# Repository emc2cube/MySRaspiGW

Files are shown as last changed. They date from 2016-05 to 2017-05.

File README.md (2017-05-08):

MySRaspiGW
==========

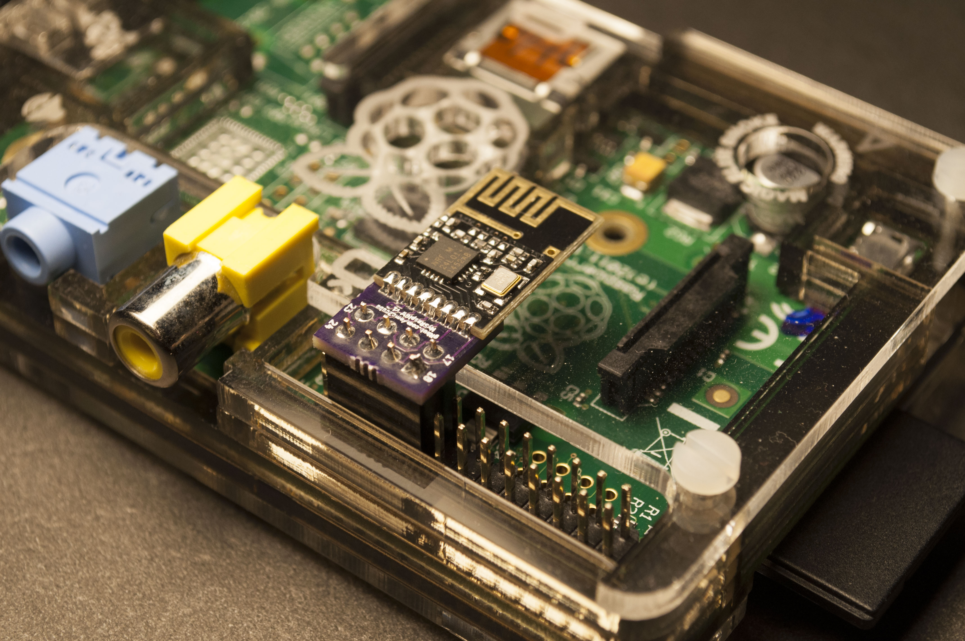
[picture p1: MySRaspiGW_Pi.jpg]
GW on the Pi

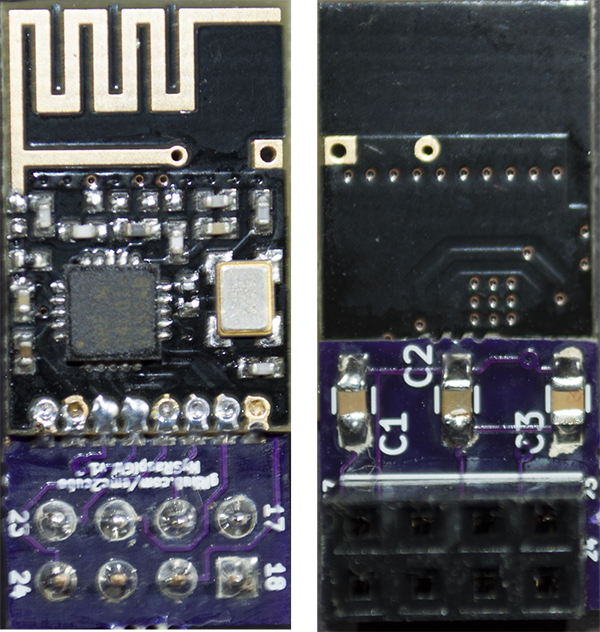
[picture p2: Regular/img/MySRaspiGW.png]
Regular GW

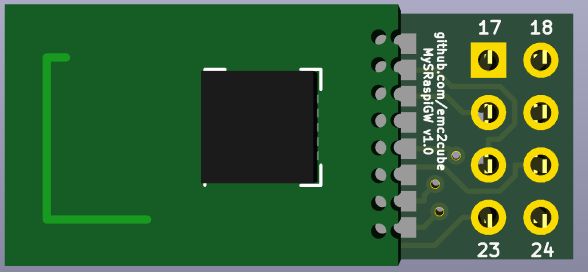
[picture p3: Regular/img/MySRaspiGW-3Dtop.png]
KiCad 3D view


Description
-----------

[MySensors](http://www.mysensors.org) SMD gateway (nRF24L01, 2.4GHz) designed to fit Raspberry Pi GPIO ports.
This is the SMD shrunk version of GertSanders [Raspberry Pi2 GPIO interface for NRF24L01+](https://www.openhardware.io/view/17/Raspberry-Pi2-GPIO-interface-for-NRF24L01).

Ordering and options
--------

Four different models are available, differences being the radio used (standard or PA+LNA modules) and the PCB shape.

### Standard nRF24L01 module version:
- Regular version is the smallest form factor available. Radio module is straight with GPIO pins.
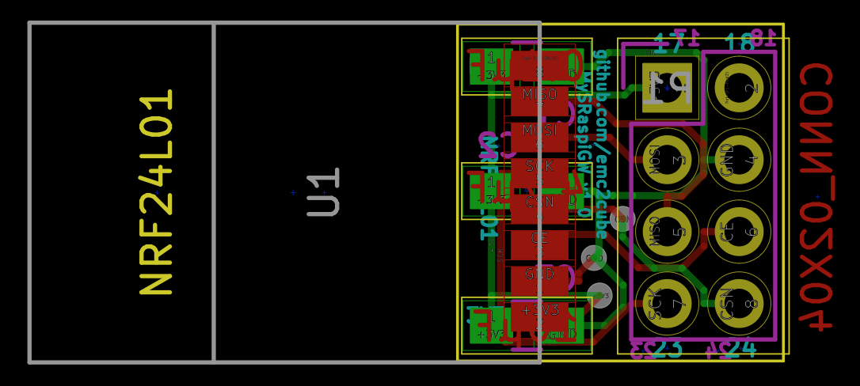
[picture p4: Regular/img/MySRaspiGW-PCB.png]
MySRaspiGW regular PCB


- Pimoroni version is designed to fit inside the popular [Pimoroni](http://pimoroni.com) cases designed for the original Raspberry Pi model B, such as [Pibow](https://www.raspberrypi.org/blog/pibow/).
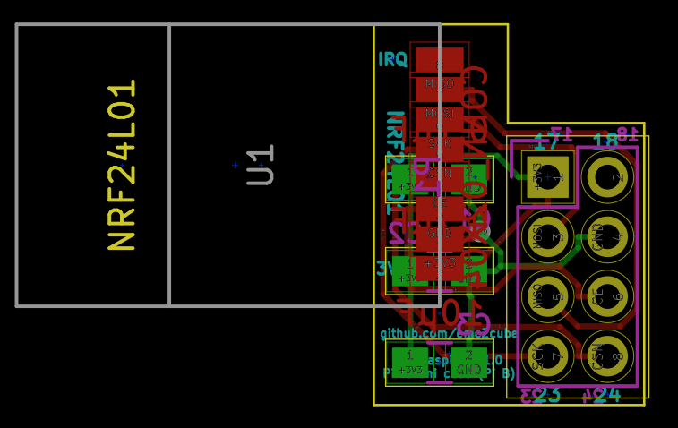
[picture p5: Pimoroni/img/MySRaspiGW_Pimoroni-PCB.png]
MySRaspiGW Pimoroni PCB


The regular version can be [ordered directly assembled](https://www.openhardware.io/order/105/ASMBL1X) ($20) on [openhardware.io](https://www.openhardware.io/view/105/MySRaspiGW)

Gerber files are included for both versions so you can order these PCB at your favorite PCB fab house and solder the few components yourself.
For an easy ordering process you can directly order these PCB without having to do anything else:
- Regular PCB, [PCBs.io](https://pcbs.io/share/rp2W3) 4 for $0.89, black 1.6mm PCB, ENIG finish or [OSHPark.com](https://oshpark.com/shared_projects/dWrubL3S) 3 for $1.10, purple 1.6mm PCB, ENIG finish.
- Pimoroni PCB, [PCBs.io](https://pcbs.io/share/rN3VE) 4 for $1.20, black 1.6mm PCB, ENIG finish [OSHPark.com](https://oshpark.com/shared_projects/6JsJqI3E) 3 for $1.50, purple 1.6mm PCB, ENIG finish.

### Amplified nRF24L01 PA+LNA module version:
- Regular version is the smallest form factor available. Radio module is straight with GPIO pins.
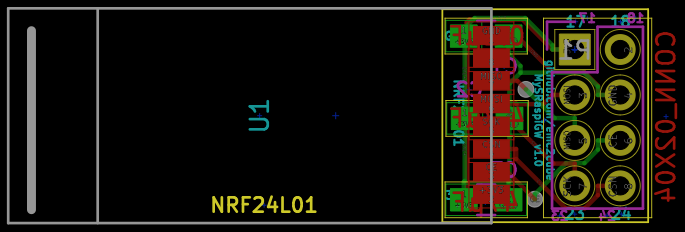
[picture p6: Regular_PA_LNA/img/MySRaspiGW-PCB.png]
MySRaspiGW regular PCB


- Pimoroni version is designed to fit inside the popular [Pimoroni](http://pimoroni.com) cases designed for the original Raspberry Pi model B, such as [Pibow](https://www.raspberrypi.org/blog/pibow/).
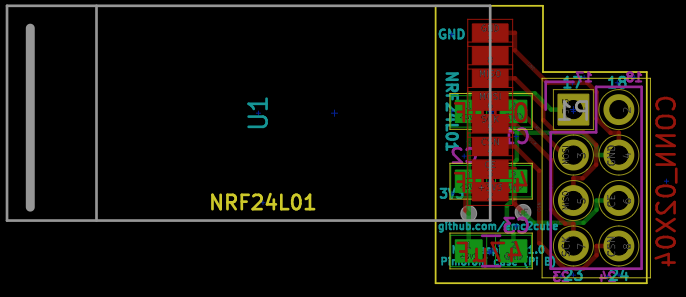
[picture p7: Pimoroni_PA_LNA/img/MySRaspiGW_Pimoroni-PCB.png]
MySRaspiGW Pimoroni PCB


The regular version can be [ordered directly assembled](https://www.openhardware.io/order/116/ASMBL1X) ($21) on [openhardware.io](https://www.openhardware.io/view/116/MySRaspiGW-PALNA)

Gerber files are included for both versions so you can order these PCB at your favorite PCB fab house and solder the few components yourself.
For an easy ordering process you can directly order these PCB without having to do anything else:
- Regular PCB, [PCBs.io](https://pcbs.io/share/4Q7e1) 4 for $0.86, black 1.6mm PCB, ENIG finish or [OSHPark.com](https://oshpark.com/shared_projects/PaP5y1X2) 3 for $1.05, purple 1.6mm PCB, ENIG finish.
- Pimoroni PCB, [PCBs.io](https://pcbs.io/share/4o2WQ) 4 for $1.15, black 1.6mm PCB, ENIG finish or [OSHPark.com](https://oshpark.com/shared_projects/2UrzYLvi) 3 for $1.40, purple 1.6mm PCB, ENIG finish.

Installation
-------

Plug the Gateway module to Raspberry Pi Pins 17 to 24 and follow the instructions on [MySensors website](https://www.mysensors.org/build/raspberry) to compile the code.
- If you are using a PA+LNA module and are experiencing some Tx errors add **--my-rf24-pa-level=RF24_PA_LOW** option to your ./configure
- V1.1: For IRQ pin support add **--my-rf24-irq-pin=18** option to your ./configure
- To be sure your pty device is easily identified by any controller use a ttyUSB name, for example add **--my-serial-pty=/dev/ttyUSBMySensorsGateway** option to your ./configure

### Serial interface (pty)
./configure --my-gateway=serial --my-serial-is-pty --my-serial-pty=/dev/ttyUSBMySensorsGateway --my-rf24-pa-level=RF24_PA_LOW --my-rf24-irq-pin=18

### Ethernet interface
./configure --my-rf24-pa-level=RF24_PA_LOW --my-rf24-irq-pin=18

Revision history
----------------

- Version 1.1: IRQ pin support.
- Version 1.0: Initial release.

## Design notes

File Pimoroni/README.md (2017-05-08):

MySRaspiGW
==========

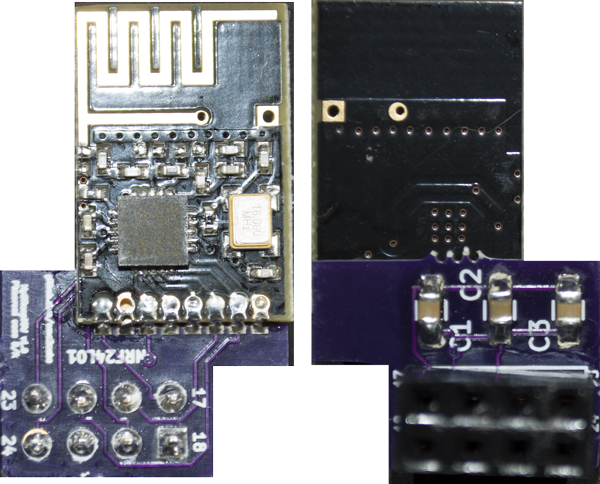
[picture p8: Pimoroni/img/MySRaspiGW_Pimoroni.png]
Pimoroni GW

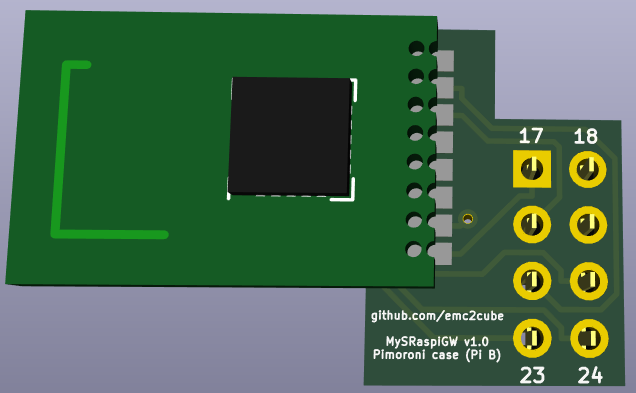
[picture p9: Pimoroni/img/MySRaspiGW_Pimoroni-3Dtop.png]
KiCad 3D top view

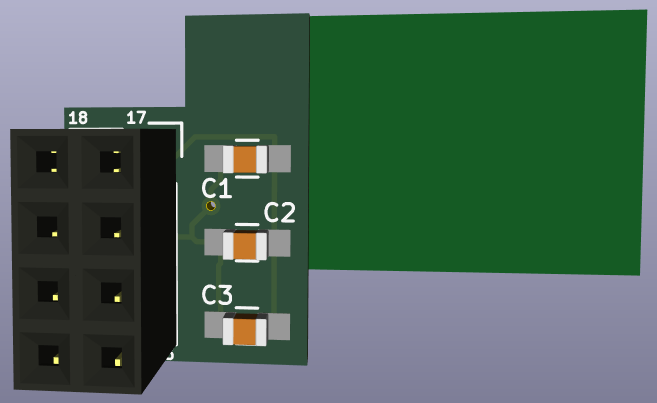
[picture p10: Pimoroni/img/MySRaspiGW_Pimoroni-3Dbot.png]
KiCad 3D bot view


Description
-----------

[MySensors](http://www.mysensors.org) SMD gateway (nRF24L01, 2.4GHz) designed to fit Raspberry Pi B GPIO ports inside a Pimoroni enclosure.
Shrunk SMD version version of GertSanders [Raspberry Pi2 GPIO interface for NRF24L01+](https://www.openhardware.io/view/17/Raspberry-Pi2-GPIO-interface-for-NRF24L01).

Ordering and options
--------

Two different models are available, only difference being the PCB shape.

This is the Pimoroni version, designed to fit inside the popular [Pimoroni](http://pimoroni.com) cases designed for the original Raspberry Pi model B, such as [Pibow](https://www.raspberrypi.org/blog/pibow/).
MySRaspiGW pimoroni Kicad PCB
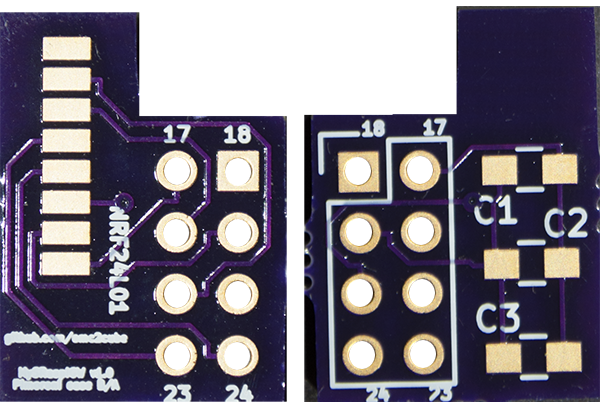
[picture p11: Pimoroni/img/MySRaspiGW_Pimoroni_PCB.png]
MySRaspiGW pimoroni PCB


A [Regular version](https://www.github.com/emc2cube/MySRaspiGW/tree/master/Regular/) is also available. It has a smaller form factor with radio module being straight with GPIO pins. It should fit most of the other raspberry Pi model B cases, and any other recent model.

Gerber files are included so you can order these PCB at your favorite PCB fab house and solder the few components yourself.
For an easy ordering process you can directly order these PCB without having to do anything else:
- [PCBs.io](https://pcbs.io/share/rN3VE) 4 for $1.20, black 1.6mm PCB, ENIG finish.
- [OSHPark.com](https://oshpark.com/shared_projects/6JsJqI3E) 3 for $1.50, purple 1.6mm PCB, ENIG finish.

Installation
-------

Plug the Gateway module to Raspberry Pi Pins 17 to 24 and follow the instructions on [MySensors website](https://www.mysensors.org/build/raspberry) to compile the code.
- V1.1: For IRQ pin support add **--my-rf24-irq-pin=18** option to your ./configure
- To be sure your pty device is easily identified by any controller use a ttyUSB name, for example add **--my-serial-pty=/dev/ttyUSBMySensorsGateway** option to your ./configure

### Serial interface (pty)
./configure --my-gateway=serial --my-serial-is-pty --my-serial-pty=/dev/ttyUSBMySensorsGateway --my-rf24-irq-pin=18

### Ethernet interface
./configure --my-rf24-pa-level=RF24_PA_LOW --my-rf24-irq-pin=18

Revision history
----------------

- Version 1.1: IRQ pin support.
- Version 1.0: Initial release.

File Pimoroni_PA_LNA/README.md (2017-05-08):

MySRaspiGW
==========

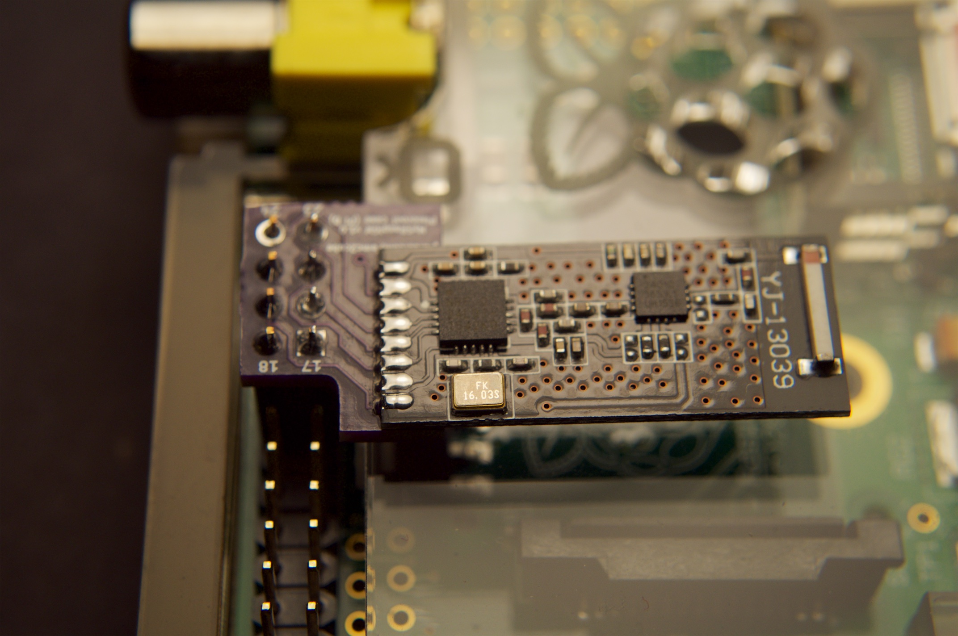
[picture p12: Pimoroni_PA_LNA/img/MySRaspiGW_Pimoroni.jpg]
Pimoroni GW

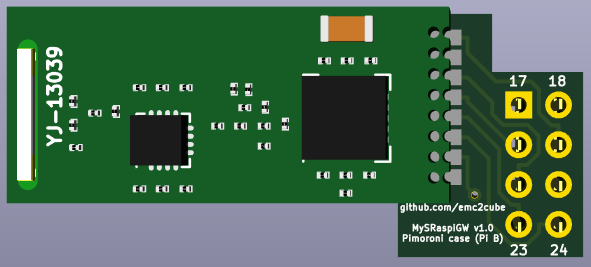
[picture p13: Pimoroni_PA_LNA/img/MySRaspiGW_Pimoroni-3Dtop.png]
KiCad 3D top view

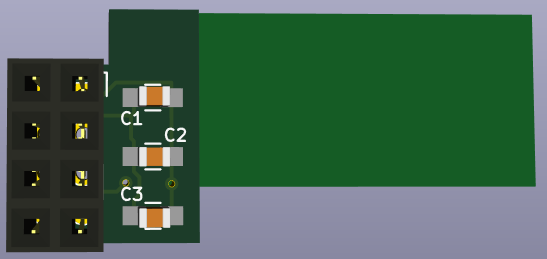
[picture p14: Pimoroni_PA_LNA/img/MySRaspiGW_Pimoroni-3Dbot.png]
KiCad 3D bot view


Description
-----------

[MySensors](http://www.mysensors.org) SMD gateway (nRF24L01 PA+LNA, 2.4GHz) designed to fit Raspberry Pi B GPIO ports inside a Pimoroni enclosure.
Shrunk PA+LNA SMD version of GertSanders [Raspberry Pi2 GPIO interface for NRF24L01+](https://www.openhardware.io/view/17/Raspberry-Pi2-GPIO-interface-for-NRF24L01).

Ordering and options
--------

Two different models are available, only difference being the PCB shape.

This is the Pimoroni version, designed to fit inside the popular [Pimoroni](http://pimoroni.com) cases designed for the original Raspberry Pi model B, such as [Pibow](https://www.raspberrypi.org/blog/pibow/).
MySRaspiGW pimoroni Kicad PCB
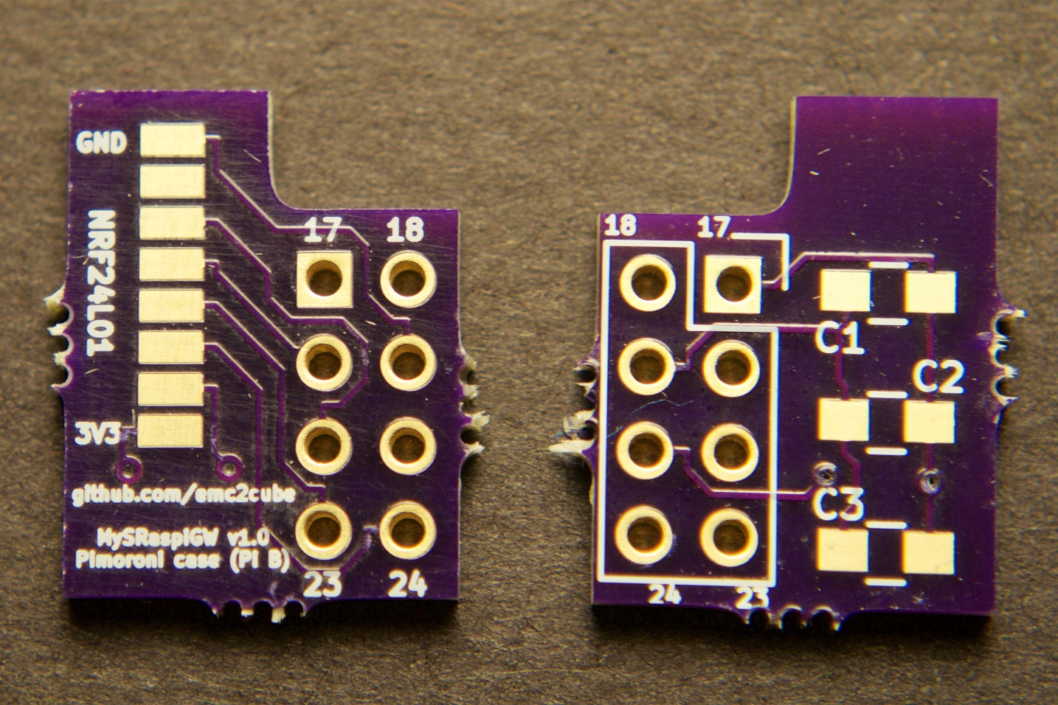
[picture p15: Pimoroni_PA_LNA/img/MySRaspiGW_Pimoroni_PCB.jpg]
MySRaspiGW pimoroni PCB


A [Regular version](https://www.github.com/emc2cube/MySRaspiGW/tree/master/Regular_PA_LNA/) is also available. It has a smaller form factor with radio module being straight with GPIO pins. It should fit most of the other raspberry Pi model B cases, and any other recent model.

Gerber files are included so you can order these PCB at your favorite PCB fab house and solder the few components yourself.
For an easy ordering process you can directly order these PCB without having to do anything else:
- [PCBs.io](https://pcbs.io/share/4o2WQ) 4 for $1.15, black 1.6mm PCB, ENIG finish.
- [OSHPark.com](https://oshpark.com/shared_projects/2UrzYLvi) 3 for $1.40, purple 1.6mm PCB, ENIG finish.

Installation
-------

Plug the Gateway module to Raspberry Pi Pins 17 to 24 and follow the instructions on [MySensors website](https://www.mysensors.org/build/raspberry) to compile the code.
- If you are using a PA+LNA module and are experiencing some Tx errors add **--my-rf24-pa-level=RF24_PA_LOW** option to your ./configure
- V1.1: For IRQ pin support add **--my-rf24-irq-pin=18** option to your ./configure
- To be sure your pty device is easily identified by any controller use a ttyUSB name, for example add **--my-serial-pty=/dev/ttyUSBMySensorsGateway** option to your ./configure

### Serial interface (pty)
./configure --my-gateway=serial --my-serial-is-pty --my-serial-pty=/dev/ttyUSBMySensorsGateway --my-rf24-pa-level=RF24_PA_LOW --my-rf24-irq-pin=18

### Ethernet interface
./configure --my-rf24-pa-level=RF24_PA_LOW --my-rf24-irq-pin=18

Revision history
----------------

- Version 1.1: IRQ pin support.
- Version 1.0: Initial release.

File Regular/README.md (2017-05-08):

MySRaspiGW
==========

Regular GW
KiCad 3D top view
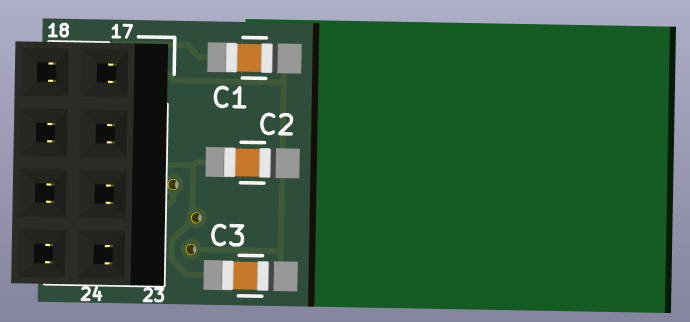
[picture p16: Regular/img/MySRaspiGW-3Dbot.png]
KiCad 3D bot view


Description
-----------

[MySensors](http://www.mysensors.org) SMD gateway (nRF24L01, 2.4GHz) designed to fit Raspberry Pi GPIO ports.
Shrunk SMD version of GertSanders [Raspberry Pi2 GPIO interface for NRF24L01+](https://www.openhardware.io/view/17/Raspberry-Pi2-GPIO-interface-for-NRF24L01).

Ordering and options
--------

Two different models are available, only difference being the PCB shape.

Regular version is the smallest form factor available. Radio module is straight with GPIO pins.
MySRaspiGW regular Kicad PCB
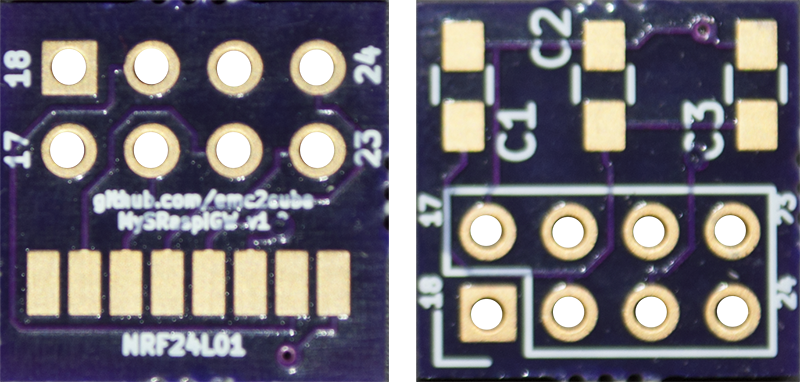
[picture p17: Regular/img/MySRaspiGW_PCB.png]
MySRaspiGW regular PCB


A [Pimoroni version](https://www.github.com/emc2cube/MySRaspiGW/tree/master/Pimoroni/) is also available, designed to fit inside the popular [Pimoroni](http://pimoroni.com) cases designed for the original Raspberry Pi model B, such as [Pibow](https://www.raspberrypi.org/blog/pibow/).

This version can be [ordered directly assembled](https://www.openhardware.io/order/105/ASMBL1X)($20) on [openhardware.io](https://www.openhardware.io/view/105/MySRaspiGW)

Gerber files are included so you can order these PCB at your favorite PCB fab house and solder the few components yourself.
For an easy ordering process you can directly order these PCB without having to do anything else:
- [PCBs.io](https://pcbs.io/share/rp2W3) 4 for $0.89, black 1.6mm PCB, ENIG finish.
- [OSHPark.com](https://oshpark.com/shared_projects/dWrubL3S) 3 for $1.10, purple 1.6mm PCB, ENIG finish.

Installation
-------

Plug the Gateway module to Raspberry Pi Pins 17 to 24 and follow the instructions on [MySensors website](https://www.mysensors.org/build/raspberry) to compile the code.
- V1.1: For IRQ pin support add **--my-rf24-irq-pin=18** option to your ./configure
- To be sure your pty device is easily identified by any controller use a ttyUSB name, for example add **--my-serial-pty=/dev/ttyUSBMySensorsGateway** option to your ./configure

### Serial interface (pty)
./configure --my-gateway=serial --my-serial-is-pty --my-serial-pty=/dev/ttyUSBMySensorsGateway --my-rf24-irq-pin=18

### Ethernet interface
./configure --my-rf24-pa-level=RF24_PA_LOW --my-rf24-irq-pin=18

Revision history
----------------

- Version 1.1: IRQ pin support.
- Version 1.0: Initial release.

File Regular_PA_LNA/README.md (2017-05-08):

MySRaspiGW
==========

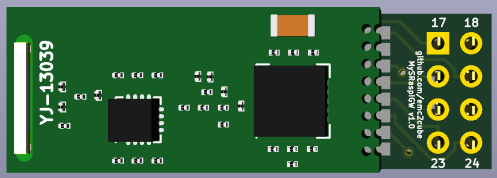
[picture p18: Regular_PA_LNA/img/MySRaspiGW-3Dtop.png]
KiCad 3D top view

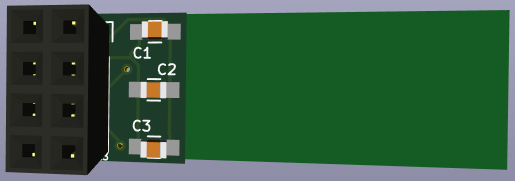
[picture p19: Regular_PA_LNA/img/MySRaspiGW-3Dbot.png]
KiCad 3D bot view


Description
-----------

[MySensors](http://www.mysensors.org) SMD gateway (nRF24L01 PA+LNA, 2.4GHz) designed to fit Raspberry Pi GPIO ports.
Shrunk PA+LNA SMD version of GertSanders [Raspberry Pi2 GPIO interface for NRF24L01+](https://www.openhardware.io/view/17/Raspberry-Pi2-GPIO-interface-for-NRF24L01).

Ordering and options
--------

Two different models are available, only difference being the PCB shape.

Regular version is the smallest form factor available. Radio module is straight with GPIO pins.
MySRaspiGW regular Kicad PCB
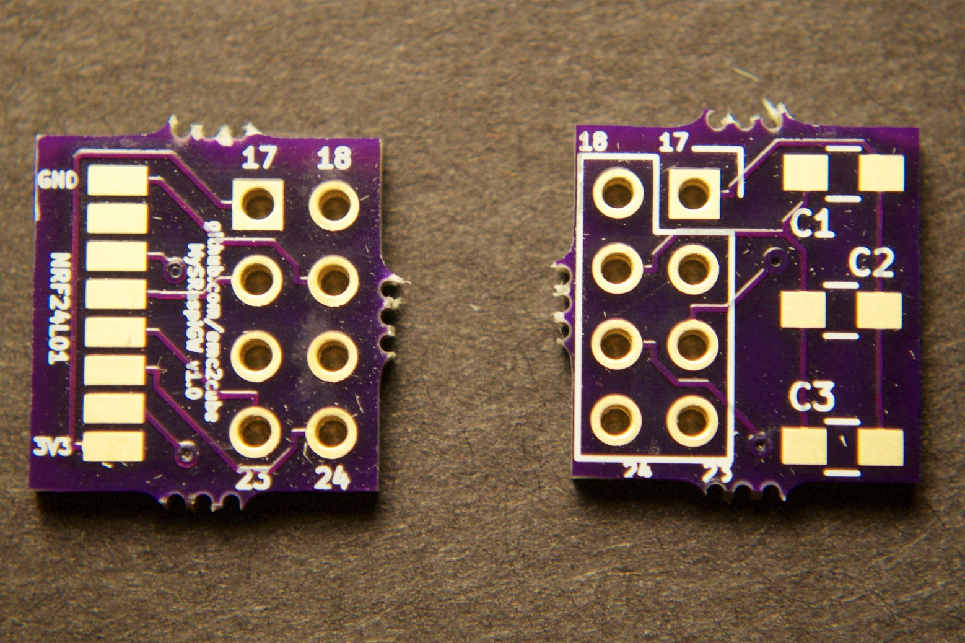
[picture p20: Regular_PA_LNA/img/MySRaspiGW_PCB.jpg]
MySRaspiGW regular PCB


A [Pimoroni version](https://www.github.com/emc2cube/MySRaspiGW/tree/master/Pimoroni_PA_LNA/) is also available, designed to fit inside the popular [Pimoroni](http://pimoroni.com) cases designed for the original Raspberry Pi model B, such as [Pibow](https://www.raspberrypi.org/blog/pibow/).

This version can be [ordered directly assembled](https://www.openhardware.io/order/116/ASMBL1X)($20) on [openhardware.io](https://www.openhardware.io/view/116/MySRaspiGW-PALNA)

Gerber files are included so you can order these PCB at your favorite PCB fab house and solder the few components yourself.
For an easy ordering process you can directly order these PCB without having to do anything else:
- [PCBs.io](https://pcbs.io/share/4Q7e1) 4 for $0.86, black 1.6mm PCB, ENIG finish.
- [OSHPark.com](https://oshpark.com/shared_projects/PaP5y1X2) 3 for $1.05, purple 1.6mm PCB, ENIG finish.

Installation
-------

Plug the Gateway module to Raspberry Pi Pins 17 to 24 and follow the instructions on [MySensors website](https://www.mysensors.org/build/raspberry) to compile the code.
- If you are using a PA+LNA module and are experiencing some Tx errors add **--my-rf24-pa-level=RF24_PA_LOW** option to your ./configure
- V1.1: For IRQ pin support add **--my-rf24-irq-pin=18** option to your ./configure
- To be sure your pty device is easily identified by any controller use a ttyUSB name, for example add **--my-serial-pty=/dev/ttyUSBMySensorsGateway** option to your ./configure

### Serial interface (pty)
./configure --my-gateway=serial --my-serial-is-pty --my-serial-pty=/dev/ttyUSBMySensorsGateway --my-rf24-pa-level=RF24_PA_LOW --my-rf24-irq-pin=18

### Ethernet interface
./configure --my-rf24-pa-level=RF24_PA_LOW --my-rf24-irq-pin=18

Revision history
----------------

- Version 1.1: IRQ pin support.
- Version 1.0: Initial release.

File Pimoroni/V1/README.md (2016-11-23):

MySRaspiGW
==========

Pimoroni GW
KiCad 3D top view
KiCad 3D bot view

Description
-----------

[MySensors](http://www.mysensors.org) SMD gateway (nRF24L01, 2.4GHz) designed to fit Raspberry Pi GPIO ports.
This is the SMD shrunk version of GertSanders [Raspberry Pi2 GPIO interface for NRF24L01+](https://www.openhardware.io/view/17/Raspberry-Pi2-GPIO-interface-for-NRF24L01).

Ordering and options
--------

Two different models are available, only difference is on the PCB shape.

This is the Pimoroni version, designed to fit inside the popular [Pimoroni](http://pimoroni.com) cases designed for the original Raspberry Pi model B, such as [Pibow](https://www.raspberrypi.org/blog/pibow/).
MySRaspiGW pimoroni Kicad PCB
MySRaspiGW pimoroni PCB

A [Regular version](https://www.github.com/emc2cube/MySRaspiGW/tree/master/Regular/) is also available. It has a smaller form factor with radio module being straight with GPIO pins. It should fit most of the other raspberry Pi model B cases, and any other recent model.

Gerber files are included so you can order these PCB at your favorite PCB fab house and solder the few components yourself.
For an easy ordering process you can directly order these PCB from [OSHPark](https://oshpark.com/shared_projects/c99XW7uq), 3 for $1.45.

Installation
-------

Plug the Gateway module to Raspberry Pi Pins 17 to 24 and follow the instructions on [MySensors forum](https://forum.mysensors.org/topic/2437/step-by-step-procedure-to-connect-the-nrf24l01-to-the-gpio-pins-and-use-the-raspberry-as-a-serial-gateway) to compile the code.

Revision history
----------------

Version 1.0: Initial release.

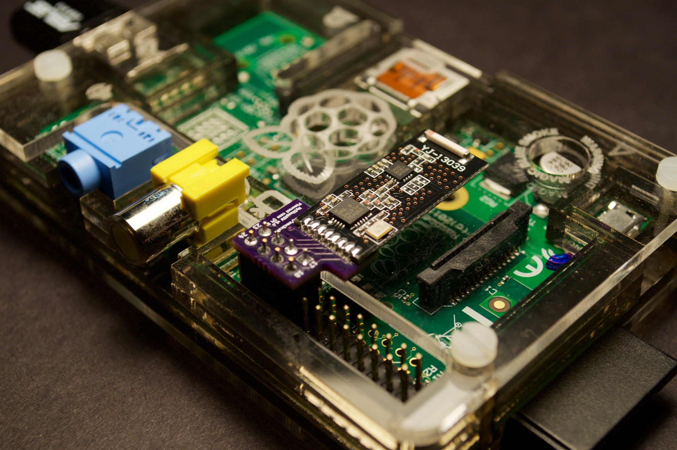
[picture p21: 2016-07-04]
MySRaspiGW_PA_LNA_Pi.jpg

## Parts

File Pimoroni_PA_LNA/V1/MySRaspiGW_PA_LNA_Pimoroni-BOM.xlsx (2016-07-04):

Quantity | Part | Value | Package | Manufacturer | Manufacturer P/N | Mouser P/N | Comment | Aliexpress or Ebay link
1 | C1 | 0.1µF | SMD 0805 | Murata | GRM21R71C104JA01D | 81-GRM21R71C104JA01D |  | http://www.aliexpress.com/item/1LOT-100PCS-Chip-Capacitors-0-1uF-104K-16V-10-0805-Package0805-2012-Metric/32560085454.html
1 | C2 | 4.7µF | SMD 0805 | Murata | GRM21BR61C475KA88K | 81-GRM21BR61C475KA8K |  | http://www.aliexpress.com/item/1LOT-100PCS-Chip-Capacitors-4-7uF-475K-16V-10-0805-Package0805-2012-Metric/32561376020.html
1 | C3 | 47µF | SMD 0805 | Murata | GRM21BR60J476ME15L | 81-GRM21BR60J476ME5L |  | http://www.aliexpress.com/item/1LOT-10PCS-Chip-Capacitors-47uF-476M-6-3V-20-0805-Package0805-2012-Metric/32560338594.html
1 | U1 | NRF24L01_PA+LNA-SMD | NRF24L01_PA+LNA-SMD |  |  |  |  | http://www.aliexpress.com/item/5pcs-lot-SMD-NRF24L01-1100-meter-long-distance-NRF24L01-PA-LNA-SMD-wireless-modules-1100meters-in/32367250849.html
1 | P1 | 2x4 pin 2.54mm pitch female header |  |  |  |  |  | http://www.aliexpress.com/item/Free-shipping-Brand-New-High-Quality-10pcs-2x4-Pin-8P-2-54mm-Double-Row-Female-Straight/32402809934.html

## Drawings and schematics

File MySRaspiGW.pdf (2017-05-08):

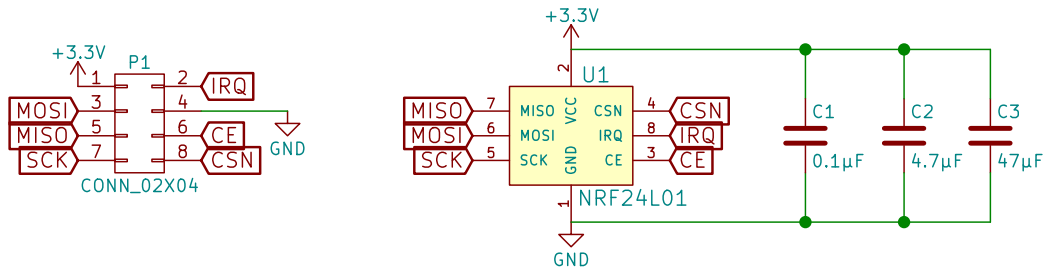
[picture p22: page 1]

2 CE 3 CSN 4 SCK 5 MOSI 6 MISO 7

MySensors Raspberry Pi SMD GPIO gateway GND

File: MySRaspiGW.sch Sheet: / https://github.com/emc2cube/MySRaspiGW/tree/master/Regular

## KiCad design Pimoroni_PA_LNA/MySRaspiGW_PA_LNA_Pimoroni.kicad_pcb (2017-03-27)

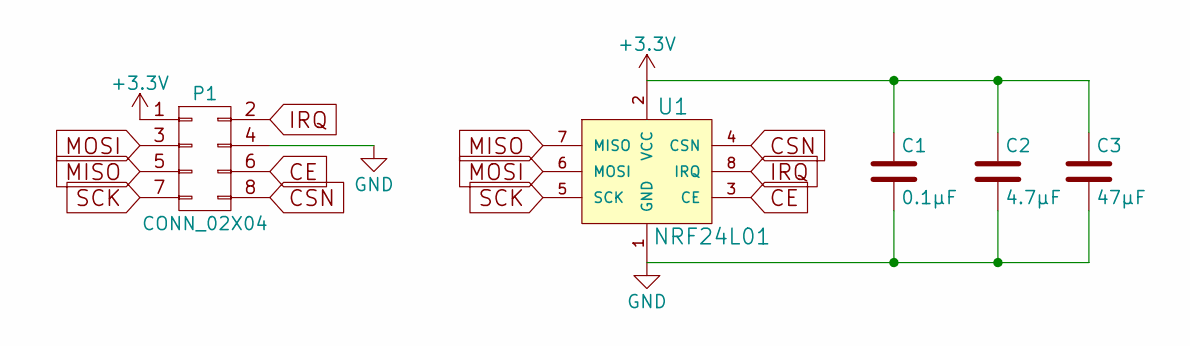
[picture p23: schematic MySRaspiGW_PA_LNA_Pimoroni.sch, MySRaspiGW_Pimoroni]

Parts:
C1: 0.1µF; C_0805_HandSoldering
C2: 4.7µF; C_0805_HandSoldering
C3: 47µF; C_0805_HandSoldering
P1: CONN_02X04; Socket_Strip_Straight_2x04
U1: NRF24L01; NRF24L01_PA_LNA-SMD

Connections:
+3V3: C1.1, C2.1, C3.1, P1.1, U1.2 (VCC)
CE: P1.6, U1.3 (CE)
CSN: P1.8, U1.4 (CSN)
GND: C1.2, C2.2, C3.2, P1.4, U1.1 (GND)
IRQ: P1.2, U1.8 (IRQ)
MISO: P1.5, U1.7 (MISO)
MOSI: P1.3, U1.6 (MOSI)
SCK: P1.7, U1.5 (SCK)

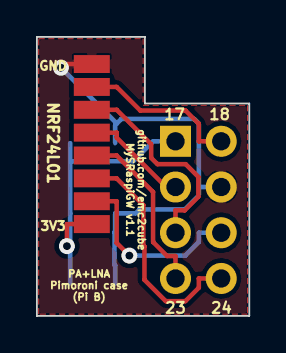
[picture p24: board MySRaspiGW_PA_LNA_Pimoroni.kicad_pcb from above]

Board: 2 copper layers, 11.8 x 15.5 mm, 5 parts (0 on the bottom side), 8 nets.

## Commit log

2016-05-30 Initial release
    Initial release
    [MySRaspiGW-BOM.xlsx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]
2016-07-04 Add PA+LNA version
    Release of a nRF24L01 PA+LNA SMD version of the gateway.
    Surprisingly working despite having a high power usage. Use with
    caution, risk of frying your GPIO ports.
    [MySRaspiGW_PA_LNA-BOM.xlsx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]
2016-11-23 MySensors V2.0 update
    Arduino code updated to be compatible with MySensors V2.0 update
2017-03-27 v1.1 IRQ support
    Added IRQ support on pin 18
    [MySRaspiGW-BOM.xlsx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]
